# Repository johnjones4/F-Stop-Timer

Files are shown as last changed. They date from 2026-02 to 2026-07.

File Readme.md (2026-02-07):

# ΔStop 100 F-Stop Timer Source Code

This is the source code to the firmware powering the ΔStop 100 F-Stop timer. It is provided as-is under the terms of the MIT license. For more, visit: https://delta100.johnjonesfour.com/



## What Is It?

ΔStop 100 is a dedicated enlarger timer that uses logarithmic, f-stop based timing instead of linear seconds. You set a base exposure in stops and every click changes exposure by a fixed fraction of a stop, so the math stays the same no matter the print size or paper type. That means faster test strips, clearer intent with every change, and less guesswork when a print needs a tiny nudge instead of a full second.

It behaves the way photographers already think: exposure as stops, not time. The interface is focused on repeatable decisions, so you can move from test to final with confidence and keep a consistent record of the choices that got you there.

## What Is F-Stop Printing?

Traditional timers measure time linearly, so the difference between 7 and 8 seconds is not the same change as the difference between 14 and 15 seconds. F-stop printing measures exposure in stops, where each step represents a doubling or halving of light.

Because each step is a constant ratio, your adjustments are predictable and comparable. Half- and third-stop changes feel natural, dodging and burning are easier to keep consistent, and notes from a previous session translate cleanly when you change paper size, contrast, or enlarger head.

ΔStop 100 applies this concept directly to the darkroom, without menus, math, or mental gymnastics. It gives you a repeatable workflow built on exposure theory you already use in the camera.

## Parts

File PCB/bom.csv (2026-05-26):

Designator | Footprint | Quantity | Value | LCSC Part #
BZ1 | Buzzer_12x9.5RM7.6 | 1 | Buzzer
C1, C14, C2, C3, C4, C5 | 1206 | 6 | 100 nF | C24497
C10, C12, C6, C7, C8, C9 | 1206 | 6 | 10nF | C1846
C11, C13 | 1206 | 2 | 22pF | C107174
D1 | 0805 | 1 | Test Interval 1 | C2295
D10 | 0805 | 1 | Print Stop 6 | C2295
D11 | 0805 | 1 | Print Stop 7 | C2295
D12 | D_SOD-123 | 1 | 1N4001 | C2892326
D13 | 0805 | 1 | ~ | C2295
D2 | 0805 | 1 | Test Interval 2 | C2295
D3 | 0805 | 1 | Test Interval 3 | C2295
D4 | 0805 | 1 | Test Interval 4 | C2295
D5 | 0805 | 1 | Print Stop 1 | C2295
D6 | 0805 | 1 | Print Stop 2 | C2295
D7 | 0805 | 1 | Print Stop 3 | C2295
D8 | 0805 | 1 | Print Stop 4 | C2295
D9 | 0805 | 1 | Print Stop 5 | C2295
DS1 | DIPS1524W100P254L3760H810Q12N | 1 | BC56-12EWA
J2 | PinSocket_1x05_P2.54mm_Vertical | 1 | Serial
J3 | CONN1x2_PJ-037A_CUD | 1 | Barrel_Jack
J4 | PinSocket_1x06_P2.54mm_Vertical | 1 | SPI
J5, J7 | CONN_MJ-3523_CUD | 2 | MJ-3523-SMT-TR | C4992553
J6 | PinSocket_1x04_P2.54mm_Vertical | 1 | I2C
Q1, Q3 | SOT-23_Handsoldering | 2 | NPN | C8512
R1, R10, R11, R14, R2, R3, R4, R5, R6, R7, R8, R9 | 1206 | 12 | 330R | C2907482
R12 | 1206 | 1 | 27k | C17943
R13, R17, R18, R19, R20, R21, R22, R23, R24, R25, R26, R27, R28, R29 | 1206 | 14 | 10k | C17902
R15, R16 | 1206 | 2 | 4.7k | C17936
R30 | 1206 | 1 | 1k | C4410
SW1 | RotaryEncoder_Bourns_Vertical_PEC12R-3x17F-Nxxxx | 1 | Base Time
SW11, SW12, SW13, SW14, SW15, SW16, SW17 | SW_SPST_B3S-1000 | 7 | SW_Push | C2733655
SW2 | RotaryEncoder_Bourns_Vertical_PEC12R-3x17F-Nxxxx | 1 | Test Interval
SW3 | RotaryEncoder_Bourns_Vertical_PEC12R-3x17F-Nxxxx | 1 | Print Stop Select
SW4 | SW_NKK_NR01 | 1 | Mode
U1, U2 | SOIC-28W_7.5x17.9mm_P1.27mm | 2 | MCP23017_SO | C47023
U4 | SOIC127P1032X265-24N | 1 | MAX7219 | C52476
U5 | SOIC8-N_MC_MCH | 1 | 24aa512-i/sn | C193702
U6 | TQFP32_32A_MCH | 1 | ATMEGA328P-AU
Y2 | Crystal_SMD_5032-2Pin_5.0x3.2mm | 1 | LFXTAL003240BULK | C112572

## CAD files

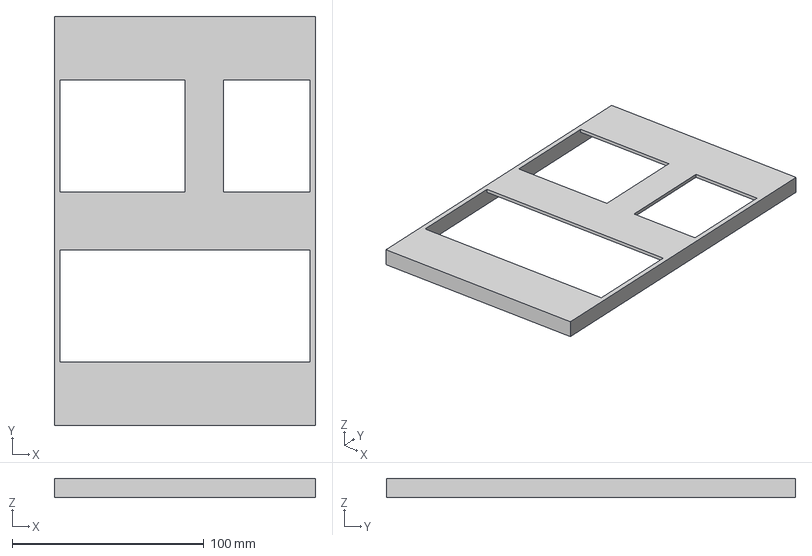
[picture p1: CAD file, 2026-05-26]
STLs/Assembly Jig.3mf
136.0 x 213.0 x 10.0 mm

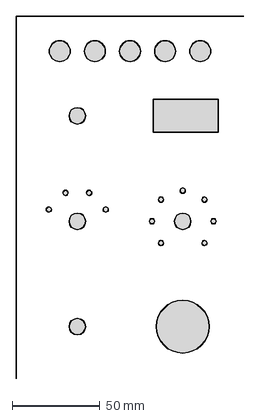
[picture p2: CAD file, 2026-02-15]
Faceplate/Panel - Cuts.dxf
129.5 x 206.5 mm

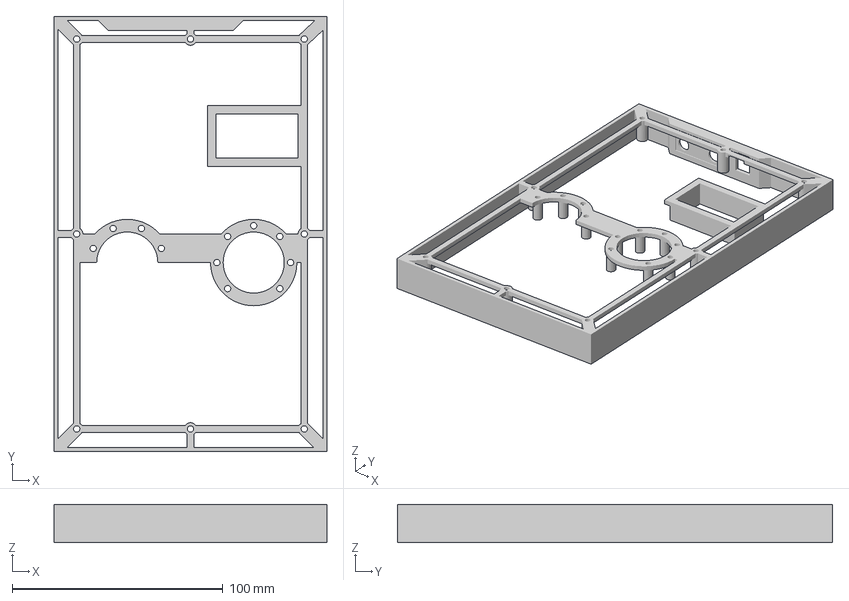
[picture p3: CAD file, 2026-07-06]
STLs/Enclosure.3mf
129.5 x 206.5 x 18.1 mm

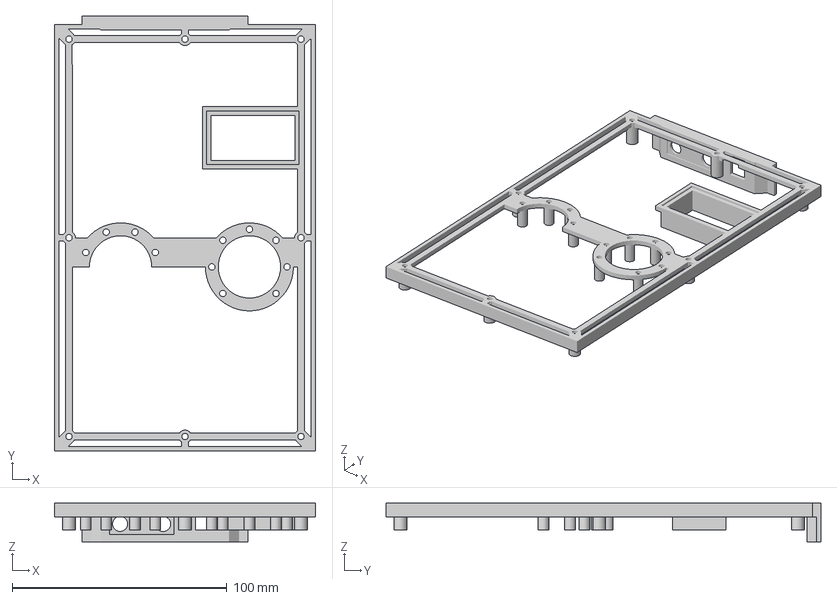
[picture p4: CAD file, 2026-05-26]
STLs/Wood Panel Chassis.3mf
121.5 x 202.5 x 18.1 mm

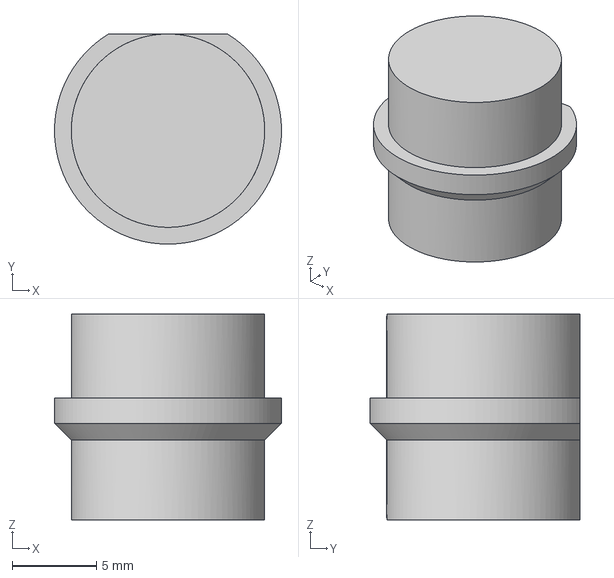
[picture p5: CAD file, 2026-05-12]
STLs/Button Small.3mf
13.5 x 12.5 x 12.3 mm

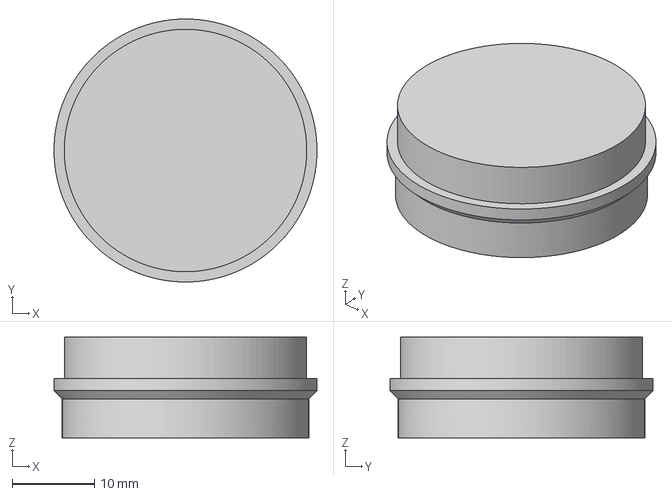
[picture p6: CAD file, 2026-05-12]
STLs/Button Large.3mf
32.0 x 32.0 x 12.3 mm

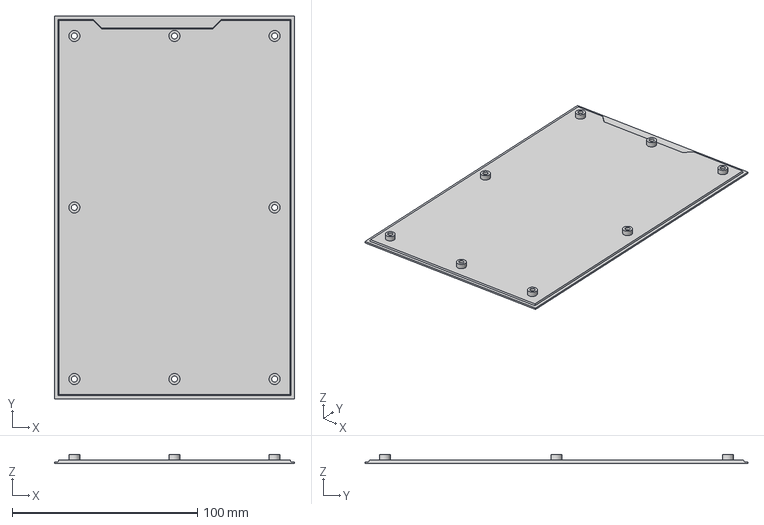
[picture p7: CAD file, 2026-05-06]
STLs/Back Plate.3mf
129.5 x 206.5 x 5.00 mm

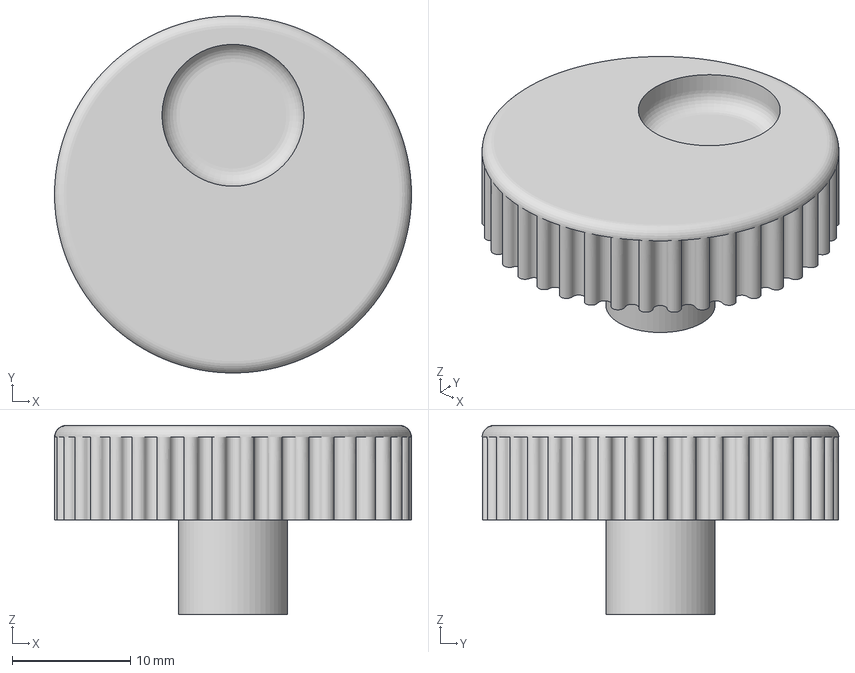
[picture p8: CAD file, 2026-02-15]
STLs/Large Knob.3mf
30.2 x 30.2 x 16.0 mm

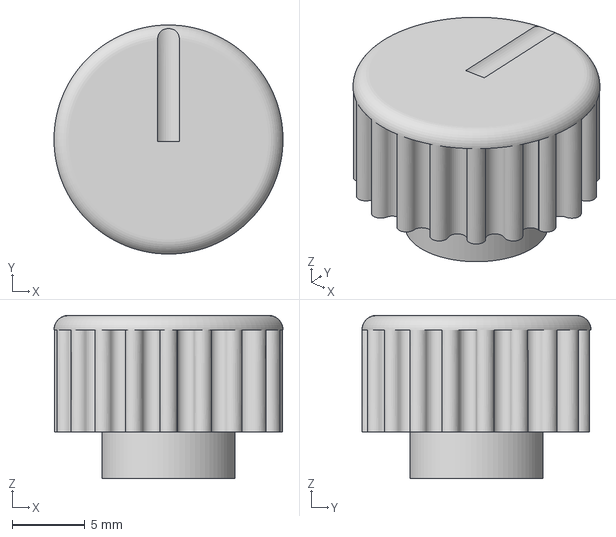
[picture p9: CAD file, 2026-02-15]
STLs/Small Knob.3mf
15.7 x 15.7 x 11.2 mm

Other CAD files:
STLs/Enclosure.stl

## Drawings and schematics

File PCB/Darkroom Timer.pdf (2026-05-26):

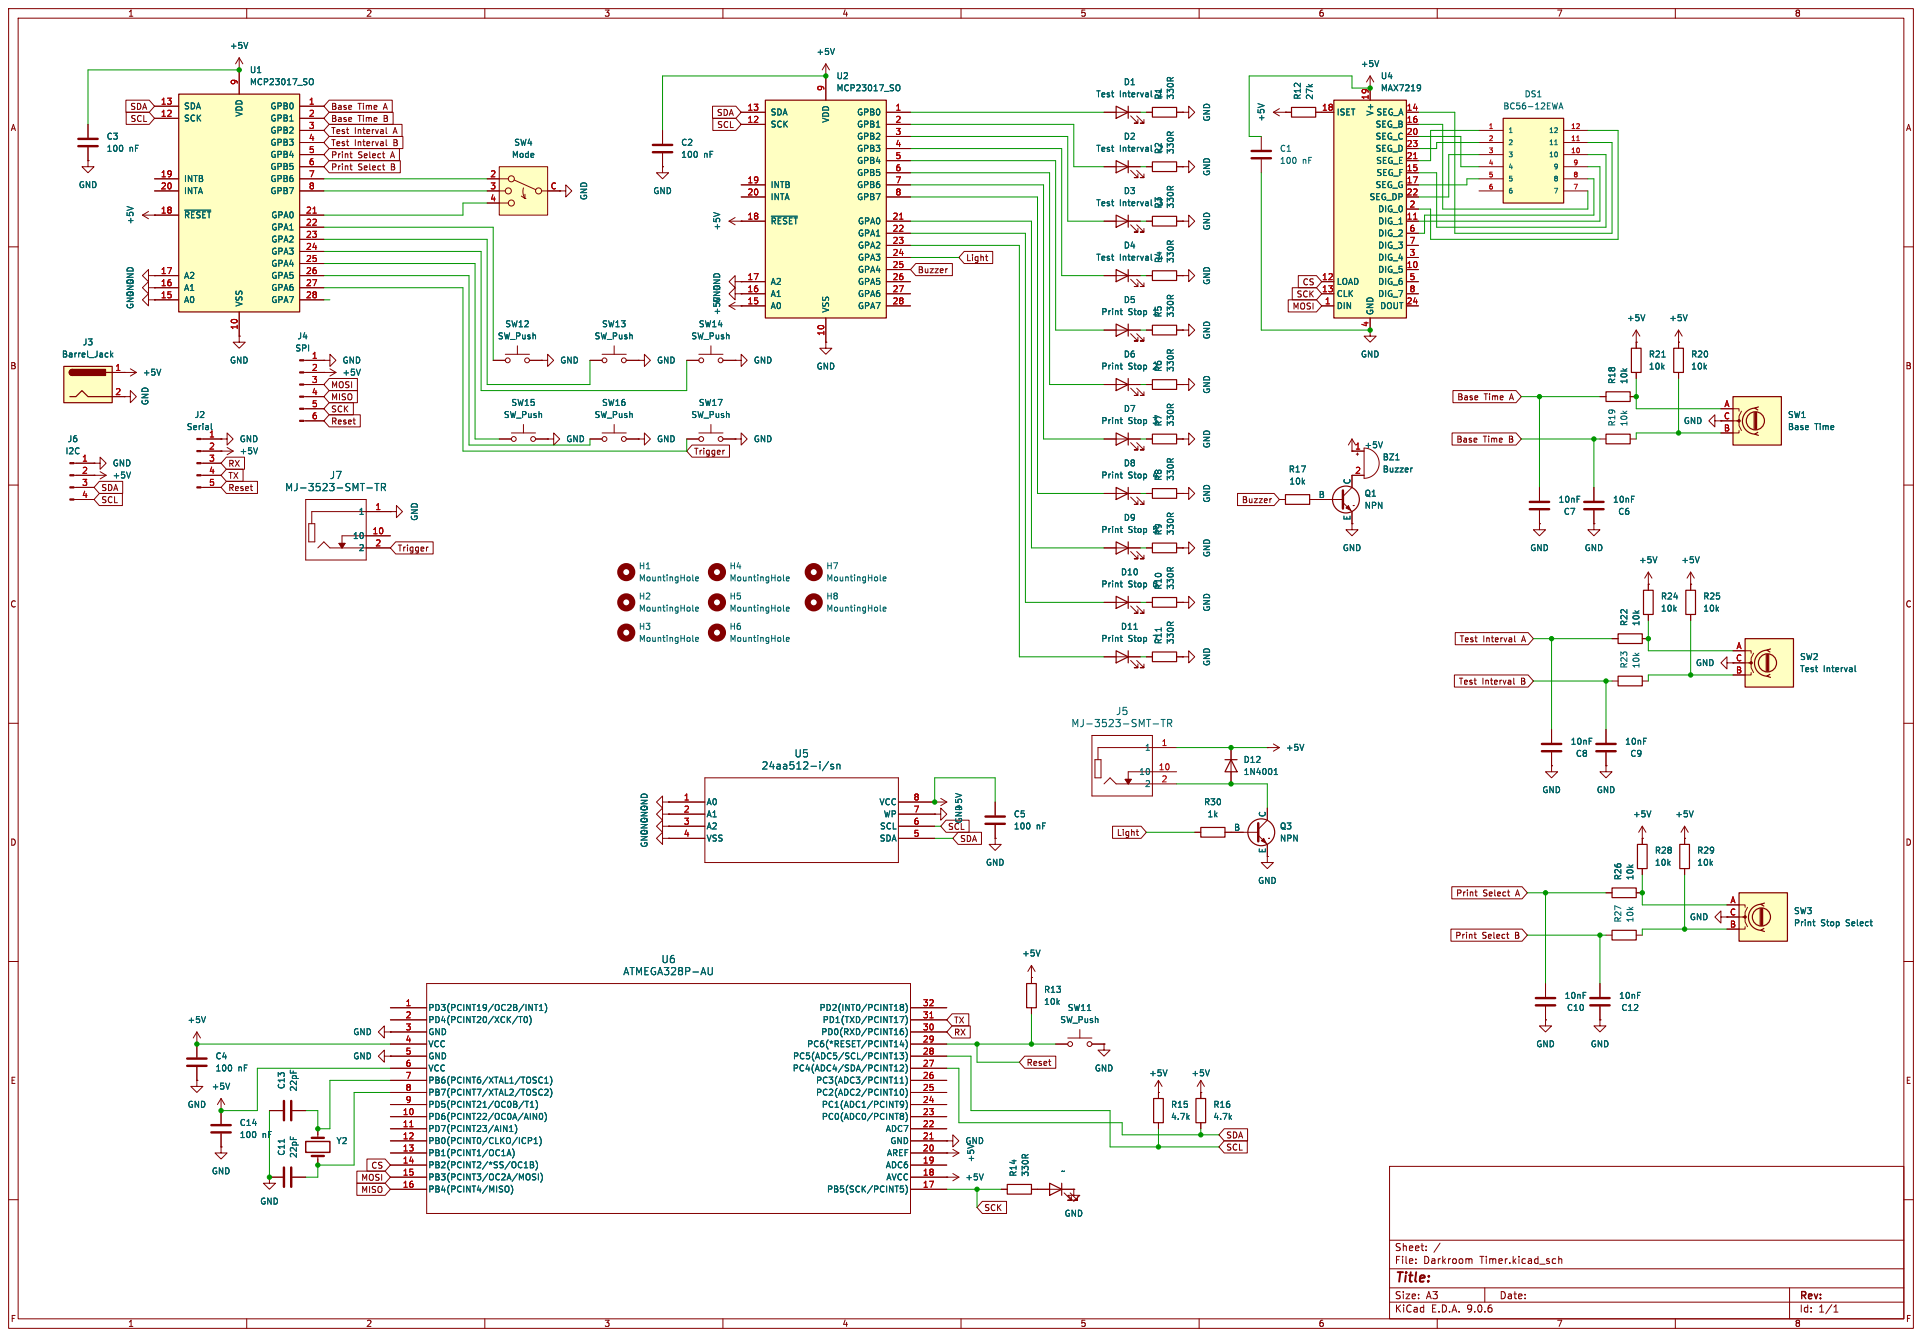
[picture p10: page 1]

4 SEG_A 14 SEG_B 16 SEG_C 20 SEG_D 23 SEG_E 21 SEG_F 15 SEG_G 17 SEG_DP 22 DIG_0 2 DIG_1 11 DIG_2 6 DIG_3 7 DIG_4 3 DIG_5 10 DIG_6 5 DIG_7 8 DOUT 24 +5V R11 330RD11 Print Stop 7 GND

SW3 Print Stop Select AC

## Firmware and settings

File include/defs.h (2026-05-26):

// #define TEST_MODE
#ifndef WASM_BUILD
#define ENABLE_EEPROM_MEMORY
#endif
// #define SCAN_I2C

// Status codes (0 = OK, nonzero = error)
#define STATUS_OK                   0
#define STATUS_INPUT_MCP_FAILED     1
#define STATUS_OUTPUT_MCP_FAILED    2
#define STATUS_EEPROM_BEGIN_FAILED  3
#define STATUS_EEPROM_NOT_CONNECTED 4

#define INPUT_ADDR 0x20
#define OUTPUT_ADDR 0x21
#define EEPROM_ADDR 0x50

#define N_STEP_INTERVALS 4
#define N_STOPS 7
#define N_BUTTONS 6
#define N_DIALS 3
#define N_MODES 3

#define ENLARGER_PIN 3
#define BUZZER_PIN 4
#define DISPLAY_CS_PIN 10

#define MAGIC_NUMBER 1989

#define STEP_INTERVALS {0.125, 0.25, 0.33, 0.5}
#define STOPS {-3, -2, -1, 0, 1, 2, 3}
#define MODE_PINS {14, 15, 0}
#define STEP_INTERVAL_PINS {8, 9, 10, 11}
#define PRINT_STOP_PINS {12, 13, 14, 15, 0, 1, 2}
#define DIAL_PINS {{9,8},{11,10},{13,12}}
#define BUTTON_PINS {1, 2, 3, 4, 5, 6}

#define POSITION_BUFFER_SIZE 2

#define BUTTON_ACTIVE_STATES {LOW, LOW, LOW, LOW, LOW, LOW}

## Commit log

2024-06-08 added pcb
2024-06-10 working times
    [F Stop Timer_contour.gm1, F Stop Timer_copperBottom.gbl, F Stop Timer_copperTop.gtl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]
2024-09-23 cad files
    [F Stop Timer.fzz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]
2024-12-17 pcb update
    [F Stop Timer.fzz]
2025-12-09 new build
    [F Stop Timer.fzz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]
2025-12-16 led fix
2026-02-08 stepper fix
2026-02-15 added STLs
    [Back Plate.3mf, Back Plate.stl, Button Large.3mf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]
2026-02-28 fab updates
    [Back Plate.3mf, Back Plate.stl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]
2026-03-21 stl updates
    [Back Plate.3mf, Back Plate.stl, Button Large.3mf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]
2026-03-25 enclosure update
    [Enclosure.3mf]
2026-05-06 fstop c file
    [Back Plate.3mf, Button Large.3mf, Button Small.3mf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]
2026-05-12 added image loader
    [Button Large.3mf, Button Small.3mf, Wood Panel Chassis.3mf]
2026-05-26 pcb updates and wasm build
    [Assembly Jig.3mf, Enclosure.3mf, Wood Panel Chassis.3mf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]
2026-07-06 added burn command
    [Enclosure.3mf]
